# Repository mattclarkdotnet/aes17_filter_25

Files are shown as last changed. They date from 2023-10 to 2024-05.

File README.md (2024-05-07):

# VERSION 2

Differences to V1:

* Space inductors out more to address excess HD3 found by @sarieri on ASR
* Change attenuator network to be independent (nearly) of the input impedance of the ADC.  This adds some switching complexity, but allows use of 1W parts continuously at 140Vrms
* Use 4-layer board to simplify layout - Ground pour is layer 2, signals are 1 & 3, with some escape traces on 4
* Replace some oversized resistors with smaller 0.25W versions and improve tolerances
* Add ground jack
* Add mounting holes to GND net - use plastic standoffs and screws if you don't want your board GND connected to the case by the screws (it will be connected anyway by the XLR sockets)
* Update to KiCad 8
* Use Mouser for BOM (done except for 4mm connectors, which Mouser doesn't have good ones of)
* Reduce baord width to 175mm
* Recommend Hammond 1444-862 case

Possible future changes:

* Switch to shielded coilcraft inductors - the issue is these have 10% tolerance instead of 5%
* Reduce Vrms goal to 60 - this is 900W into 4ohms - would allow use of smaller and cheaper parts
* Create a version with most parts SMD - this would probably not be safe into a short circuit but could be orderable through JLC
* Use LCSC for BOM to make prefab with JLC easier

# Goals

The goal is to make a cheap DIY passive filter for use in class D amp measurements, much like the AP AUX-0025.  The AP AUX-0025 specs as read off the [AP website](https://www.ap.com/analyzers-accessories/accessories/aux-family-switching-amplifier-measurement-filters/) are:
* Rejection > 50dB, 250 kHz to 20 MHz
* Frequency response +-0.05dB, 20Hz-20kHz
* Max input voltage 400V P-P (140Vrms)
* THD < -110dB

I also wanted the ability to pad down the output for high power measurements.  The resulting board looks like this:

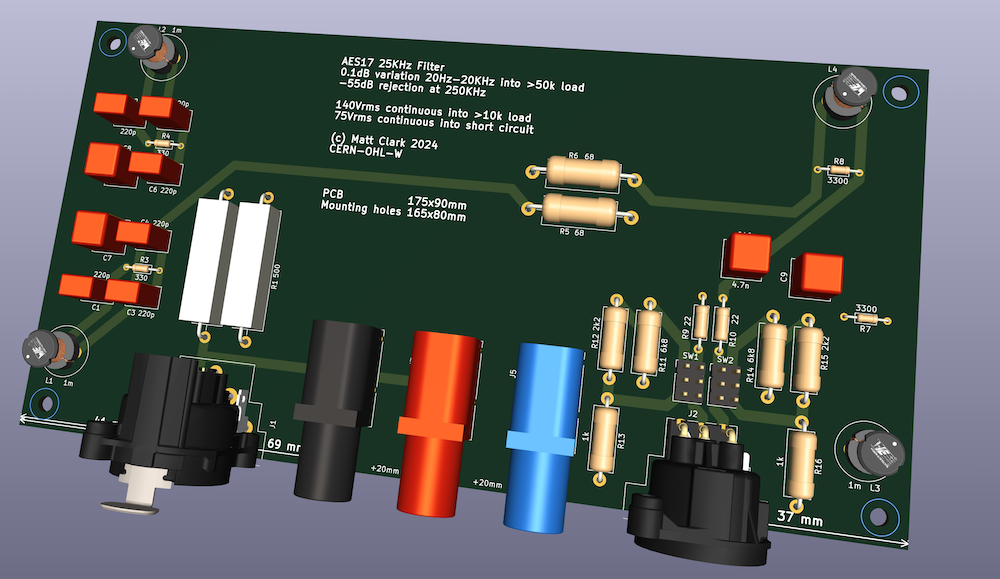
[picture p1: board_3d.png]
3D board model


# Results

- [x] Rejection > 50dB, _230_ kHz to 20 MHz
- [x] Frequency response +-0.05dB, 20Hz-20kHz
- [x] Max input voltage 400V P-P (140Vrms)
- [x] THD = _-130dB_

The simulated FR with a 100k load is on target, with -51mdBV to +51mdBV varitation from 20Hz to 20kHz, and 50dB rejection or more from 230kHz up.  The 100mdBV variation is maintained across a wide range of loads from 15k to 450k.  Measured THD is more like -130dB, so will not add to measured distortion of amplifiers, but may impact extreme resolution DAC measurements.

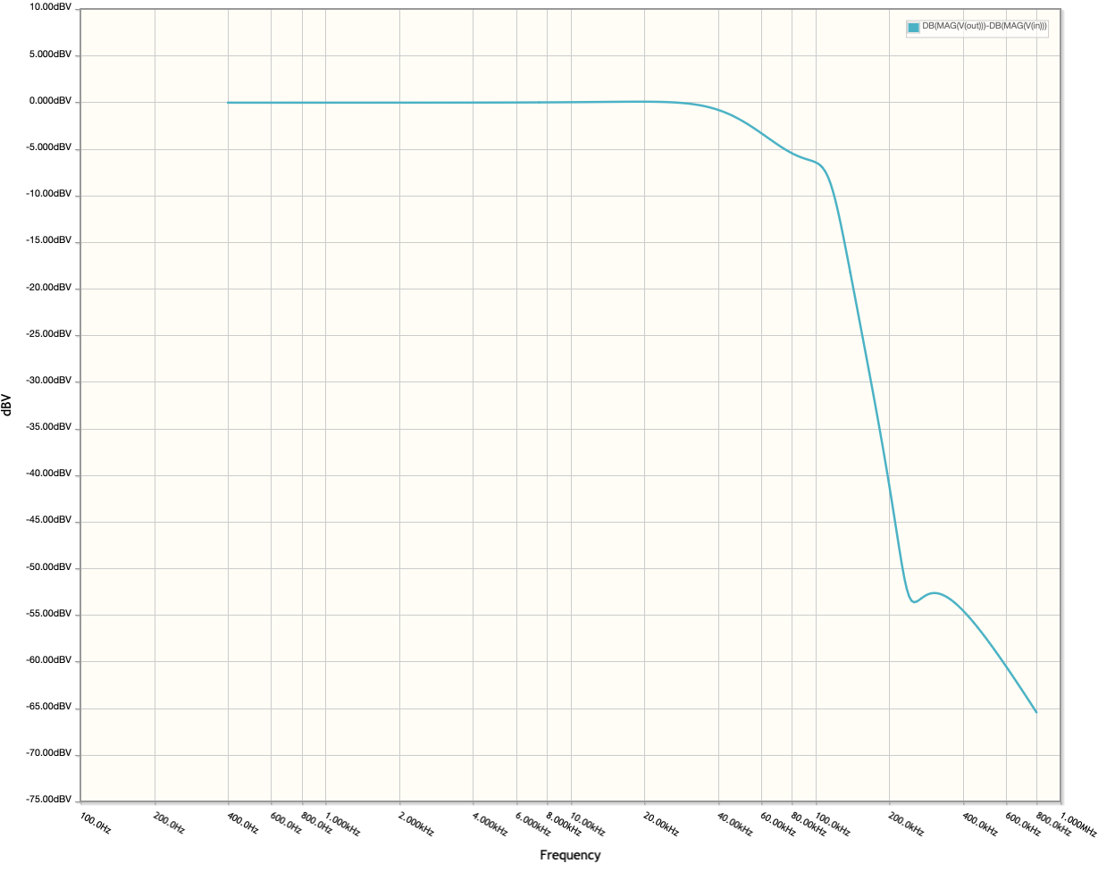
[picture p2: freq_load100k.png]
Screenshot of simulated frequency response


# Design discussion

See the design on [CircuitLab](https://www.circuitlab.com/editor/#?id=9zaq989z472b). It is inspired by the AUX-0025 but differs in a few ways.  The component values are more standard, and are reused across the design to reduce the number of different components needed.  Inductor tolerances are 5% instead of 2.5%, but resistors are all 1% and the 220p capacitors are 2.5%.  The matching to the AUX-0025 response curve is very close.

A set of pad-down resistors allows for convenient high voltage measurements, by default giving -20dB of gain.

The load impedance should be >50kOhm for best performance, but a 10kOhm load is still +-0.1dB 20Hz-20kHz, albeit with 0.4dBV of insertion loss.

Pin 1 on each XLR socket is connected to a ground pour on layer 2 of the PCB, as are the XLR chassis grounding pins.  The board should be mounted in an all metal case.

A brief short circuit, even with a high voltage applied, should be OK. The 500R/3W input resistors can take a steady state 75Vrms indefinitely ($75V^2/1000R=5.6W$), although the inductors will clearly saturate unless a reasonable load is connected to limit the current to 800mA. The 140Vrms requirement into more reasonable loads is met by the voltage ratings of the capacitors. In the case of C1 and C2 this provides a rated 500Vpp between signal rails.

# Build tips

You will need to add your own switch to the build for the voltage divider. If not using this then jumper the connections. The BOM doesn't include the pin headers for the pad-down resistor switch connections, presumably if you are building this then you have those already.

If you want to use different components then you will need to ensure you model them from scratch, e.g. if changing the inductors you will need to model the changed series resistance.  

Case choice is up to you, as cost and availability varies a lot by location, but it must be all metal with all parts connected electrically.  A Hammond 1444-862 is a good choice!

# BOM

* R1,R2 500ohm 5W 1% [https://au.mouser.com/ProductDetail/Vishay-Draloric/PAC500005000FAC000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] 25x6.4mm
* R3,R4 330ohm 0.25W 1% [https://au.mouser.com/ProductDetail/TE-Connectivity-Holsworthy/LR0204F330R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] 3.5x2mm
* R5,R6 68ohm 1W 1% [https://au.mouser.com/ProductDetail/Vishay-Dale/CMF6568R000FKR6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] 14.5x4.5mm
* R7,R8 3.3k 0.25W 1% [https://au.mouser.com/ProductDetail/KOA-Speer/MF1-4DCT52R3301F?qs=2ayCeu1TP5leCJLPVwsFCg%3D%3D] 3.5x2mm
* R9,R10 22ohm 0.25W 1% [https://au.mouser.com/ProductDetail/TE-Connectivity-Holsworthy/LR1F22R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] 6.2x2.3mm
* R11,R12 2k7 1W 1% [https://au.mouser.com/ProductDetail/YAGEO/MFR1WSFTF52-2K7?qs=xZ%2FP%252Ba9zWqZMHNDyFGZwSA%3D%3D] 9x3.3mm
* R13,R14 1k8 1W 1% [https://au.mouser.com/ProductDetail/YAGEO/MFR1WSFTF52-1K8?qs=xZ%2FP%252Ba9zWqYtbloc%2Fjj38w%3D%3D] 9x3.3mm
* C1,C2,C3,C4,C5,C6 220p 250VDC 2.5% [https://au.mouser.com/ProductDetail/WIMA/FKP2J002201D00HSSD?qs=WI052HLiD5hzJhR9QL5EAQ%3D%3D] 7.2x4.5mm, 5mm pin
* C7,C8,C9,C10 4.7n 250VDC 5% [https://au.mouser.com/ProductDetail/WIMA/FKP2F014701I00JA00?qs=WI052HLiD5hCY8ty427gtg%3D%3D] 7.2x6.5mm, 5mm pin
* L1,L2,L3,L4 1u 1ohm 800mA [https://au.mouser.com/ProductDetail/Wurth-Elektronik/7687480102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] 10.5mm dia, 5mm pin
* J1 XLR female NC3FAAH2 [https://au.mouser.com/ProductDetail/Neutrik/NC3FAAH2?qs=jCymNF74TgW4A7eq9uxuLg%3D%3D]
* J2 XLR male NC3MAAH [https://au.mouser.com/ProductDetail/Neutrik/NC3MAAH?qs=jCymNF74TgXgh2x3smwFTg%3D%3D]
* J3,J4,J5 test connectors (https://au.element14.com/cliff-electronic-components/fcr7350r/socket-pcb-4mm-r-a-s16n-pc-red/dp/1854508)

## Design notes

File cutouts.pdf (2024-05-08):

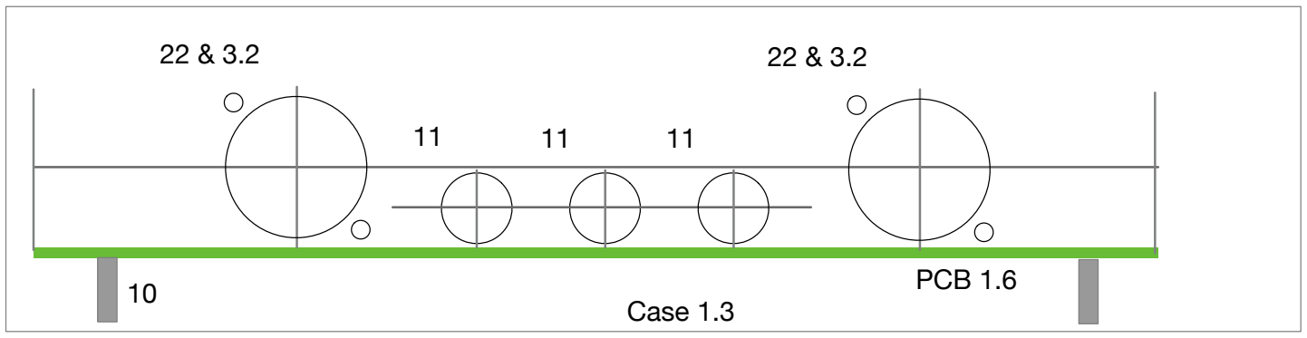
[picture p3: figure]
PCB 1.6; Case 1.3

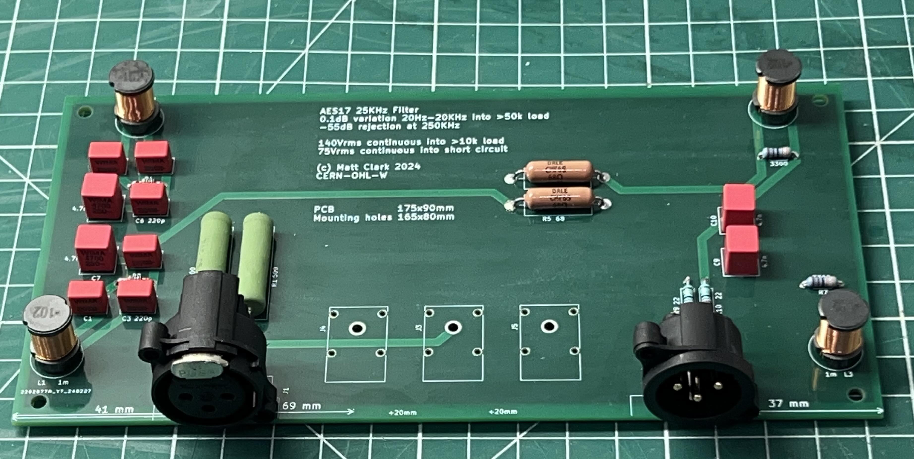
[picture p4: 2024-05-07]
v2 board.jpg

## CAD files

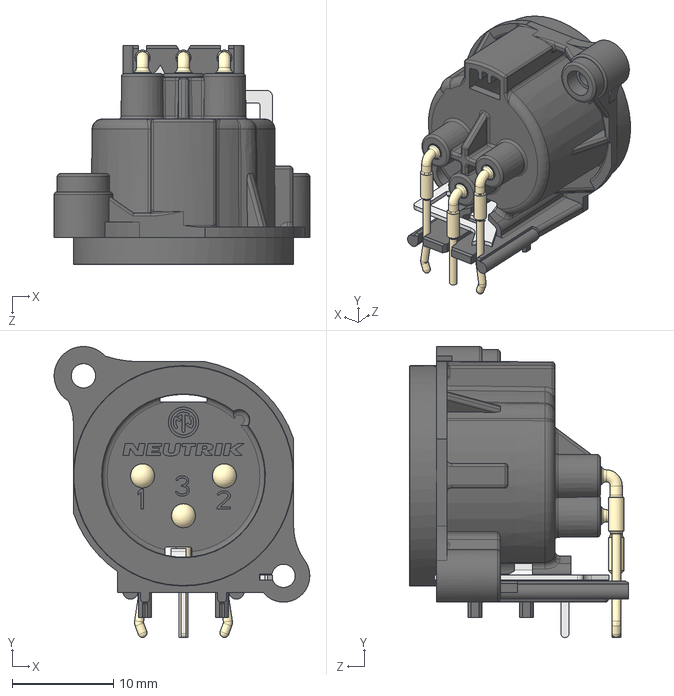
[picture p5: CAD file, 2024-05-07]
3d/Neutrik NC3MAH-0.STEP
25.3 x 28.8 x 21.7 mm

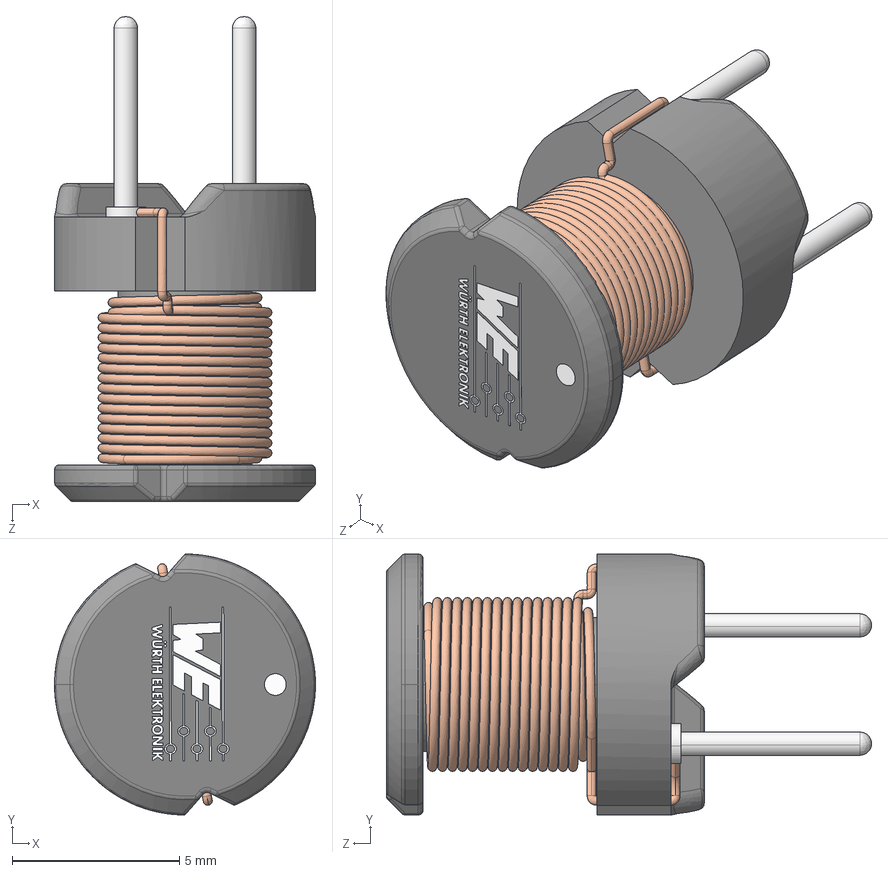
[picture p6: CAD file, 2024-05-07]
3d/7447480102.stp
7.80 x 7.80 x 14.5 mm
Kern_4
Kern_4_2
Pin_5 x 2
Wurth Logo

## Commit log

2023-08-06 Moved kicad files to subdirectory
    [aes17_filter_25.kicad_pcb, aes17_filter_25.kicad_sch]
2023-08-06 tidied BOM
2023-08-08 Added GND connections to capacitor mid-points
    [aes17_filter_25-B_Cu.gbl, aes17_filter_25-B_Mask.gbs, aes17_filter_25-B_Paste.gbp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]
2023-08-15 Added cutout diagram, improved some PCB layouts, updated readme
2023-08-15 Readme updated
    [aes17_filter_25.kicad_pcb]
2023-10-04 simplified diode switch to 1pst, fixed R7 and R8 footprints
    [aes17_filter_25.kicad_pcb, aes17_filter_25.kicad_sch]
2023-10-18 Removed protection diodes, updated readme
    [aes17_filter_25.kicad_pcb, aes17_filter_25.kicad_sch]
2023-10-24 Narrowed the board by 10mm, added images, updated readme
2023-10-24 Shrank board width, added images, updated readme
    [aes17_filter_25.kicad_pcb]
2023-10-24 Removed 3d model of output XLR
    [aes17_filter_25.kicad_pcb]
2023-10-24 Fixed typo in 3d board image link
2023-11-17 Updated 3d board image
2023-11-17 Raytraced the board and updated the wording
2024-02-24 Updated based on ASR commentary. See README for details
    [aes17_filter_25.kicad_pcb, aes17_filter_25.kicad_sch]
2024-02-24 spaced inductors out more, added ground jack
    [aes17_filter_25.kicad_pcb, aes17_filter_25.kicad_sch]
2024-02-24 Fixed minor errors, added 3d models
    [Neutrik NC3MAH-0.STEP, aes17_filter_25.kicad_pcb]
2024-02-24 reduce baord width by 5mm, add recommended hammond case to readme, move mounting holes to be 5mm inboard, change spec text on board silkscreen
    [aes17_filter_25.kicad_pcb]
2024-02-24 Added 3D models for Wurth inductors
    [7447480102.stp, aes17_filter_25.kicad_pcb]
2024-02-26 closing in on final design for v2
    [aes17_filter_25.kicad_pcb, aes17_filter_25.kicad_sch]
2024-02-26 added power calc spreadsheet
    [power and current.xlsx]
2024-02-26 updated board image
2024-02-26 moved L1 and L3 further away from XLR sockets
    [aes17_filter_25.kicad_pcb]
2024-02-28 added post-filter attenuator network
    [aes17_filter_25.kicad_pcb, aes17_filter_25.kicad_sch, power and current.xlsx]
